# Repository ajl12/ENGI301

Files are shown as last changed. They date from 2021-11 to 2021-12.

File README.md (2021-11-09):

# Stress Buddy

The following repository contains files required to operate the Stress Buddy device created using a PocketBeagle.

For more information on how to build the device and connect hardware, visit: https://www.hackster.io/ajl12/stress-buddy-12f85d

# Initializing the PocketBeagle

To initialize the PocketBeagle, perform the following commands in the terminal:

1. sudo apt-get update
2. sudo apt-get install build-essential python-dev python-setuptools python-smbus -y
3. git clone https://github.com/adafruit/adafruit-beaglebone-io-python

# Code

To setup the code, pull the following repository from GitHub: https://github.com/ajl12/ENGI301

In the project_1 folder, 3 files are required to run the device. 

1. The configure_pins.sh file should be used by running the following command in the LINUX terminal:

	chmod 755 configure_pins.sh run

2. The project_1.py file contains the main code for running the device. 

3. The run file is needed to start the device. When ready to run the device, change directories  to var/lib/cloud9/ENGI301/project_1 and type the ./run command into the terminal. 

	Note: The run file also includes a python path to reference the ht16k33.py files under var/lib/cloud9/ENGI301/python

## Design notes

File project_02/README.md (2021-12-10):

# Stress Buddy

The following repository contains EAGLE, Gerber, and documentation files required to create a PCB for the Stress Buddy device.

To learn more about the Stress Buddy device and obtain instructions for low-fidelity breadboard assembly, visit: https://www.hackster.io/ajl12/stress-buddy-12f85d

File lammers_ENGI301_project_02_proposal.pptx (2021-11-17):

## ENGI 301 Stress Buddy PCB Proposal

11/16/21
Alex Lammers

## Background Information

- Stress Buddy Prototype
  - A toy that sits on your desk and with the push of a button, signals to your coworkers that you are stressed.
  - Main Hardware Components:
    - PocketBeagle Board
    - Transistor Array
    - Push Button
    - 4-Digit 7-Segment Display
    - 0-1 PSI Analog Pressure Sensor
    - Normally Closed Solenoid Valve
    - DC 3V Micro Vacuum Air Pump

Project Documentation Links
Hackster: https://www.hackster.io/ajl12/stress-buddy-12f85d
GitHub repository: https://github.com/ajl12/ENGI301/tree/main/project_1
What changes (if any) are you going to make based on your prototype?
Removing NPN transistor and incorporating it into the transistor array

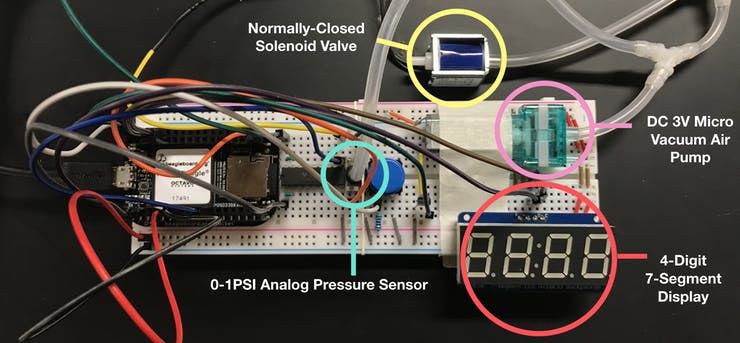
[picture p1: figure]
Main electrical hardware components of Stress Buddy.

## System Block Diagram

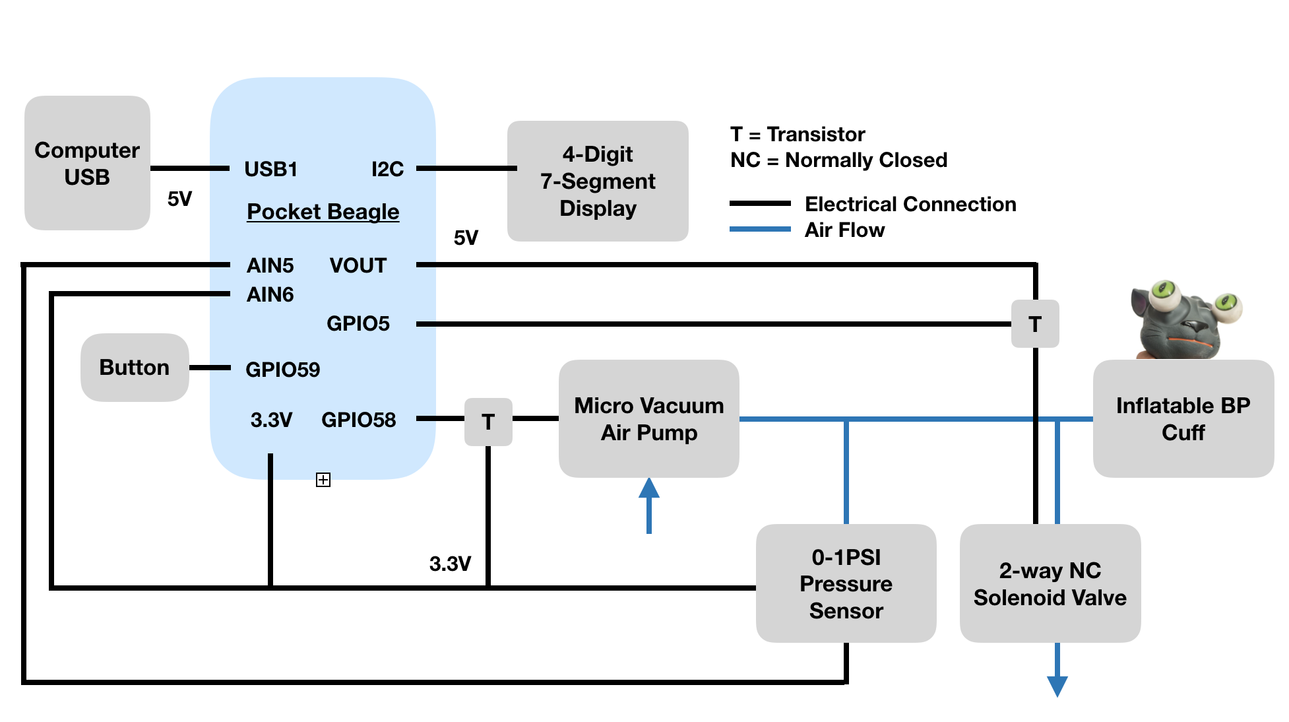
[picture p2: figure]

## Mechanical Block Diagram

Air tubing

2”

Hex Display

4”

Pocket Beagle

FRONT

1.1”

ULN2803AN

ULN2803AN

P1

3”

Solenoid Valve

Air Pump

BACK

Push
Button

USB

P2

1.38”

PS

2.17”

(primarily user interface components)

(components connected to tubing)

## Components Required

- List:
    - PocketBeagle Board
    - ULN2803AN Transistor Array
    - Push Button
    - Adafruit 0.56” 4-Digit 7-Segment Display
    - ABPDANN001PGAA5 0-1 PSI Analog Pressure Sensor
    - Normally Closed Solenoid Valve
    - DC 3V Micro Vacuum Air Pump

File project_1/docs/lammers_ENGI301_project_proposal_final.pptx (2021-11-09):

## ENGI 301

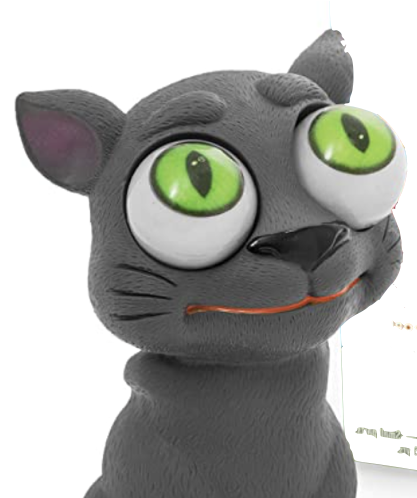
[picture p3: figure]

Stress Level

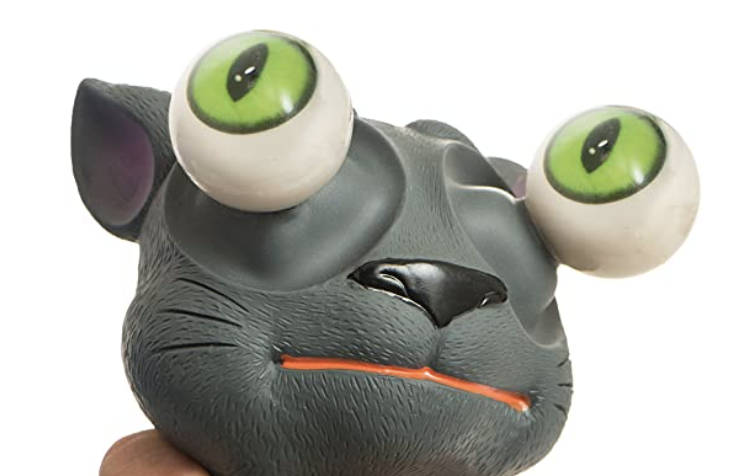
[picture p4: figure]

Stress Level

Stress-Level Indicator

10/05/13
Alex Lammers

## Background Information

Stress Level

- Working from home has naturally provided people their separate space to cope with work-related stress.
  - As people transition back to working in the office, there is a need for a light-hearted way of indicating that you still need your individual space during stressful times.
- Previous Projects to Draw On
  - Python Pressure Transducer Calibration with Manometer (https://github.com/makerportal/python-pressure-cal)
  - Blood Pressure Monitor (https://www.instructables.com/Blood-Pressure-Monitor/)
- Additions to Previous Projects
  - Holding a constant pressure through solenoid valve activation
  - Calculating pressure based voltage signals from analog pressure sensor.

Main Components:
- Solenoid valve
- Air pump
- Pressure Sensor
- Blood Pressure Cuff

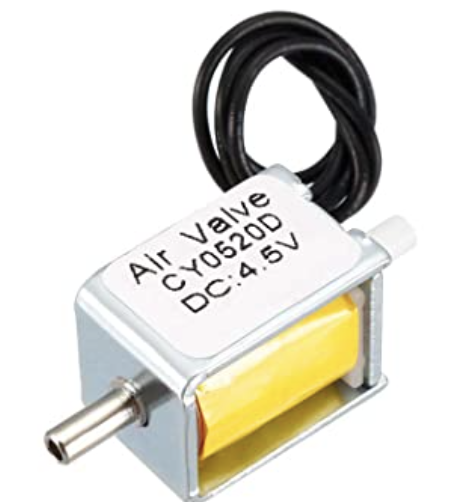
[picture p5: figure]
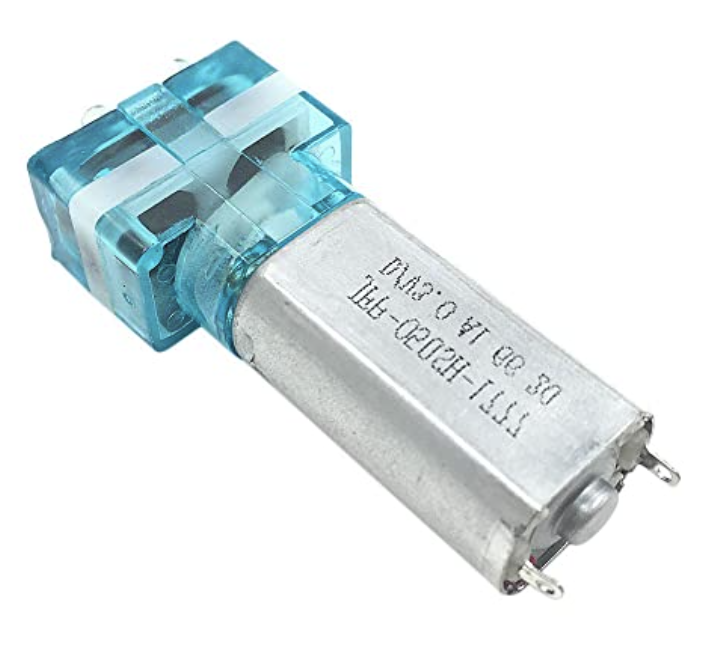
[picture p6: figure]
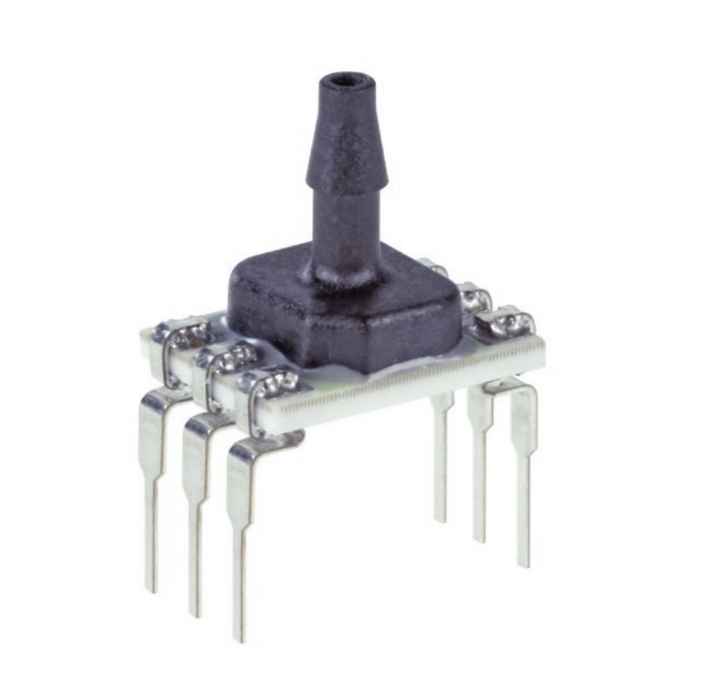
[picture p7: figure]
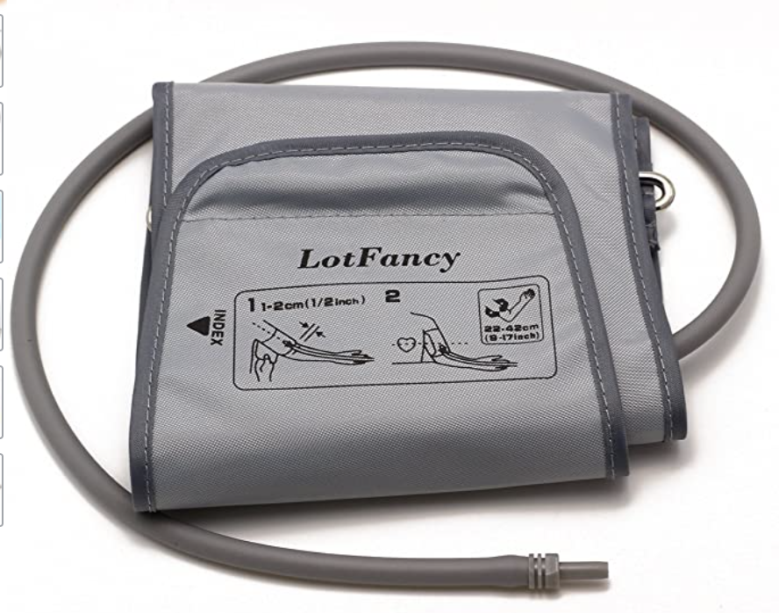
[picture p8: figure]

## System Block Diagram


Operating Procedure
1. User pushes button initiating start of air pump, pressure sensor measures pressure, LCD displays funny messages based on pressure readings
2. User pushes button again to pause inflation
3. User presses button again, solenoid opens, cuff fully decompresses

## Power Block Diagram

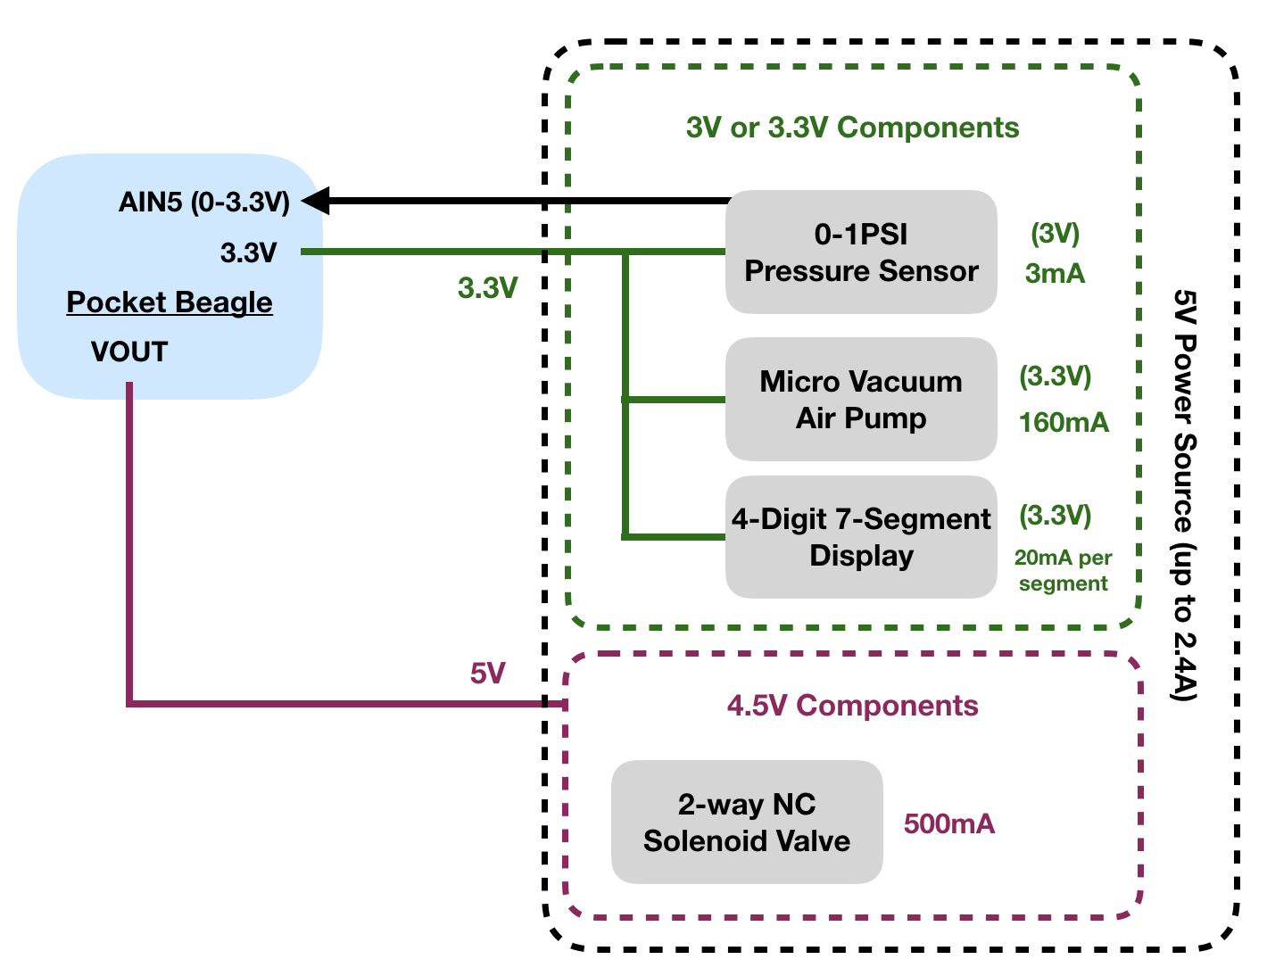
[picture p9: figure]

## Components / Budget

Component | Need to Buy | Cost
Lotfancy Large 9-17" D Ring Cuff Replacement (https://www.amazon.com/dp/B01FS37XP8) | 1 order | $10
AIMELIAE 1PCS DC 3V Micro Vacuum Air Pump Mini Air Pressure Pump Medical Pump 30KPa 0.28L (https://www.amazon.com/AIMELIAE-Micro-Vacuum-Pressure-Medical/dp/B074T95GGX) | 1 order | $12
uxcell Miniature Solenoid Valve 2 Way Normally Closed DC4.5V 0.5A Air Solenoid Valve, 2pcs (https://www.amazon.com/uxcell-Miniature-Solenoid-Normally-Closed/dp/B07WR8S4S1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) | 1 order (2 pieces) | $10
Honeywell Board Mount Pressure Sensor (https://www.mouser.com/ProductDetail/Honeywell/ABPDANN001PGAA5?qs=pAQS8nDEJVqzw9x6mmP6Eg%3D%3D)ABPDANN001PGAA5 (https://www.mouser.com/ProductDetail/Honeywell/ABPDANN001PGAA5?qs=pAQS8nDEJVqzw9x6mmP6Eg%3D%3D) | 1 order | $25
Feelers 2mm ID x 4mm OD High-Strength Silicone Tubing Thick Food Grade High Temp Pure Silicon Tube High Temp Home Brewing Winemaking Silicone Hose Tubing, 9.84ft Length (https://www.amazon.com/Feelers-High-Strength-Silicone-Silicon-Winemaking/dp/B08L81LM5B?s=industrial) | 1 order | $8
5000mAh 5V External Battery Power Pack 0.22lb (https://www.amazon.com/Alongza-Portable-Charger-10000mAh-External/dp/B082X53VDL?s=electronics) | 1 order | $20
Flippy Kitten Eye Popping Cat - Squishy Squeeze Toy for Stress Reduction (https://www.amazon.com/dp/B078KLTH1R) | 1 order | $14
| Total: | $99

Need all components to be purchased by instructor listed; additional components may be purchased by student

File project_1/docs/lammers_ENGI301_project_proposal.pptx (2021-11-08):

## ENGI 301


Stress Level


Stress Level

Stress-Level Indicator

10/05/13
Alex Lammers

## Background Information

Stress Level

- Working from home has naturally provided people their separate space to cope with work-related stress.
  - As people transition back to working in the office, there is a need for a light-hearted way of indicating that you still need your individual space during stressful times.
- Previous Projects to Draw On
  - Python Pressure Transducer Calibration with Manometer (https://github.com/makerportal/python-pressure-cal)
  - Blood Pressure Monitor (https://www.instructables.com/Blood-Pressure-Monitor/)
- Additions to Previous Projects
  - Holding a constant pressure through solenoid valve activation
  - Rescaling operational amplifier for 0-1.8V analog input pin

Main Components:
- Solenoid valve
- Air pump
- Pressure Sensor
- Blood Pressure Cuff


## System Block Diagram

Operating Procedure
1. User turns potentiometer until LCD displays desired pressure
2. User pushes button initiating start of air pump, 1st solenoid opens, LCD display continuously displays pressure
3. Pressure sensor detects desired pressure, 1st solenoid closes
4. User presses button again, 2nd solenoid opens, cuff fully decompresses

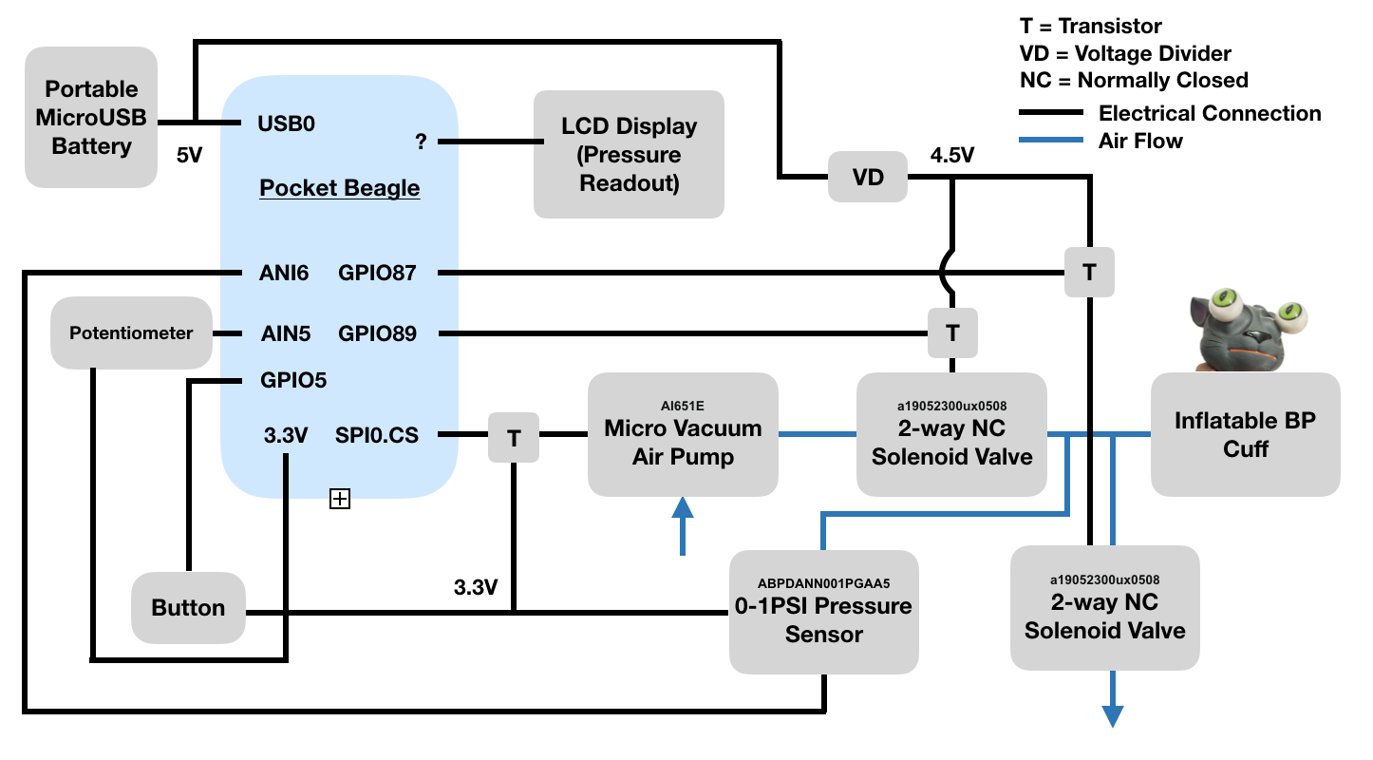
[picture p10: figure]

## Power Block Diagram

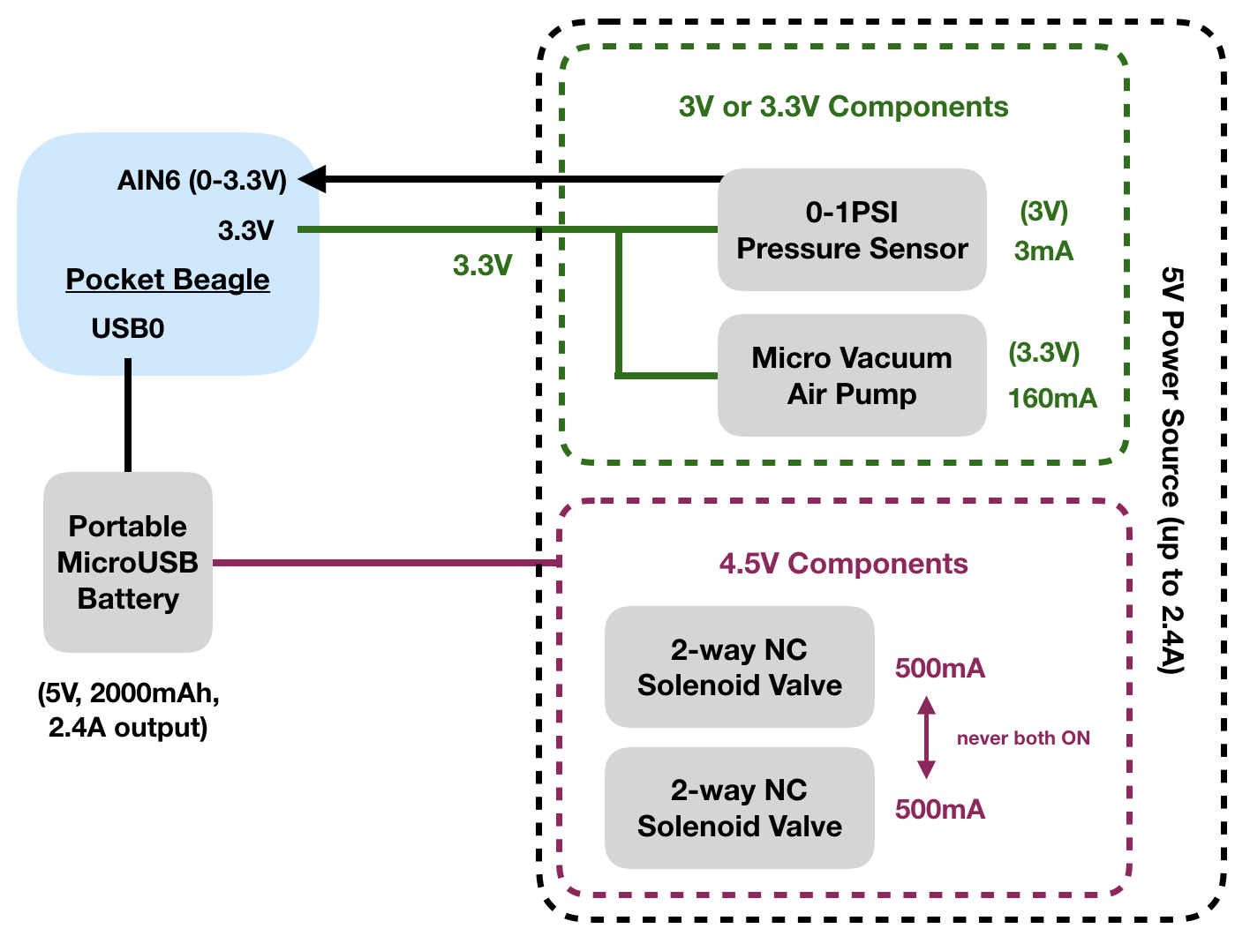
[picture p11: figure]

## Components / Budget

Component | Need to Buy | Cost
Lotfancy Large 9-17" D Ring Cuff Replacement (https://www.amazon.com/dp/B01FS37XP8) | 1 order | $10
AIMELIAE 1PCS DC 3V Micro Vacuum Air Pump Mini Air Pressure Pump Medical Pump 30KPa 0.28L (https://www.amazon.com/AIMELIAE-Micro-Vacuum-Pressure-Medical/dp/B074T95GGX) | 1 order | $12
uxcell Miniature Solenoid Valve 2 Way Normally Closed DC4.5V 0.5A Air Solenoid Valve, 2pcs (https://www.amazon.com/uxcell-Miniature-Solenoid-Normally-Closed/dp/B07WR8S4S1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) | 1 order (2 pieces) | $10
Honeywell Board Mount Pressure Sensor (https://www.mouser.com/ProductDetail/Honeywell/ABPDANN001PGAA5?qs=pAQS8nDEJVqzw9x6mmP6Eg%3D%3D)ABPDANN001PGAA5 (https://www.mouser.com/ProductDetail/Honeywell/ABPDANN001PGAA5?qs=pAQS8nDEJVqzw9x6mmP6Eg%3D%3D) | 1 order | $25
Feelers 2mm ID x 4mm OD High-Strength Silicone Tubing Thick Food Grade High Temp Pure Silicon Tube High Temp Home Brewing Winemaking Silicone Hose Tubing, 9.84ft Length (https://www.amazon.com/Feelers-High-Strength-Silicone-Silicon-Winemaking/dp/B08L81LM5B?s=industrial) | 1 order | $8
5000mAh 5V External Battery Power Pack 0.22lb (https://www.amazon.com/Alongza-Portable-Charger-10000mAh-External/dp/B082X53VDL?s=electronics) | 1 order | $20
Flippy Kitten Eye Popping Cat - Squishy Squeeze Toy for Stress Reduction (https://www.amazon.com/dp/B078KLTH1R) | 1 order | $14
| Total: | $99

Need all components to be purchased by instructor listed; additional components may be purchased by student

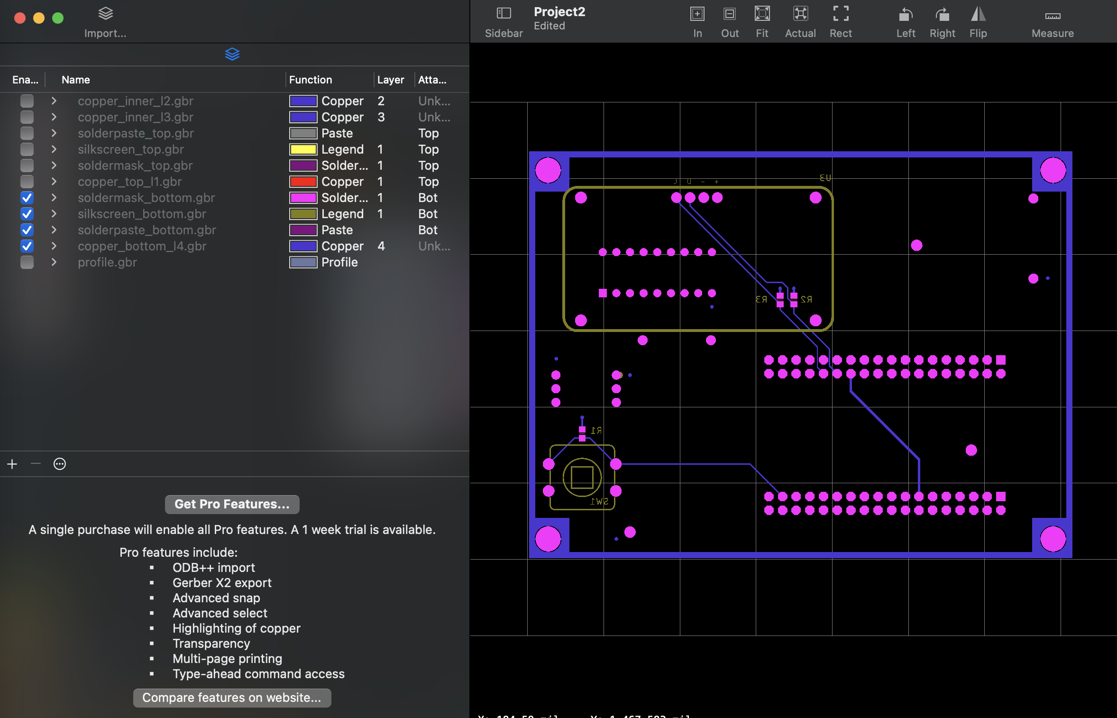
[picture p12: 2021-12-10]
project_02/docs/bottom_gerber.png

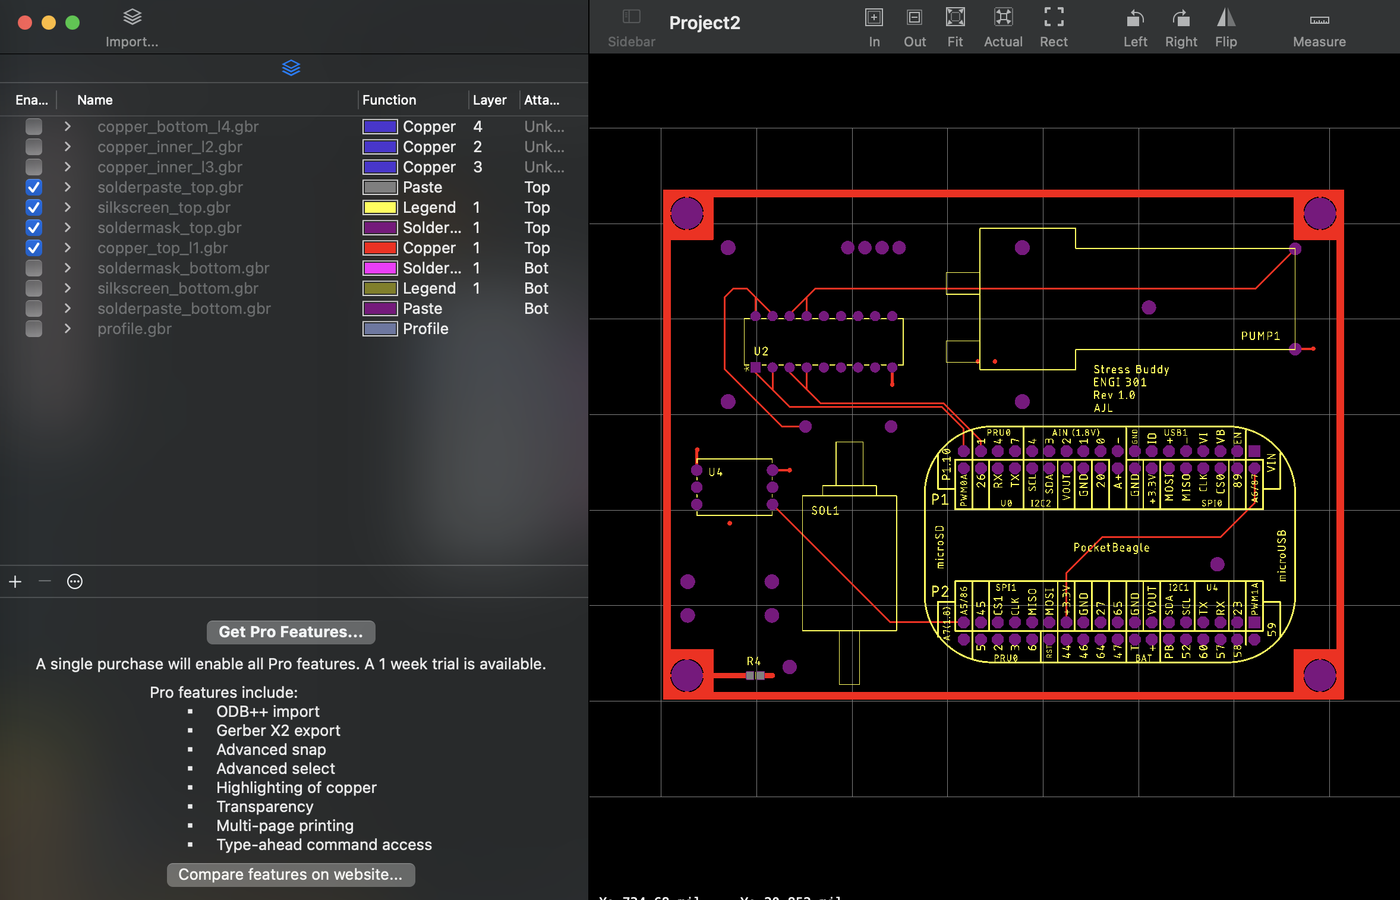
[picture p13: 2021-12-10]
project_02/docs/top_gerber.png

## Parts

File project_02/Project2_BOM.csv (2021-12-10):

Qty | Value | Device | Package | Parts | Description | COPYRIGHT | MANUFACTURER_PART_NUMBER | MFR_NAME
1 | 0.1 | R_R0603 | R0603 | R4 | RESISTOR, American symbol
1 | 0.56_HEX_BACKPACK | 0.56_HEX_BACKPACK | 0.56_HEX_BACKPACK | U3 | 0.56 LED HEX Backback - Adafruit HT16K33 -"
3 | 1k | R_R0603 | R0603 | R1, R2, R3 | RESISTOR, American symbol
1 | ABPDANT001PGAA5 | ABPDANT001PGAA5 | ABPDAN_HNW | U4 |  | Copyright (C) 2021 Ultra Librarian. All rights reserved. | ABPDANT005PGAA5 | Honeywell
1 | AIRPUMP | AIRPUMP | AIRPUMP | PUMP1 | AIMELIAE 1PCS DC 3V Micro Vacuum Air Pump Mini Air Pressure Pump Medical Pump 30KPa 0.28L -
6 | FIDUCIAL | FIDUCIAL | FIDUCIAL_40MIL | FUD1, FUD2, FUD3, FUD4, FUD5, FUD6
4 | MOUNTING_HOLE | MOUNTING_HOLE | MOUNTING_HOLE | MGT1, MGT2, MGT3, MGT4 | Chassis Mounting Hole w/GND connection ability
1 | POCKETBEAGLE_REL | POCKETBEAGLE_REL | POCKETBEAGLE | U1 | A PocketBeagle device with relevant components for the Stress Buddy project separated from the main schematic.
1 | PUSH_BUTTON | PUSH_BUTTON | BUTTON_12.5MM | SW1
1 | SOLENOID | SOLENOID | SOLENOID | SOL1 | Uxcell Miniature Solenoid Valve 2 Way Normally Closed DC4.5V 0.5A Air Solenoid Valve -
1 | ULN2803AN | ULN2803AN | N18_TEX | U2 |  | Copyright (C) 2021 Ultra Librarian. All rights reserved. | ULN2803AN | Texas Instruments

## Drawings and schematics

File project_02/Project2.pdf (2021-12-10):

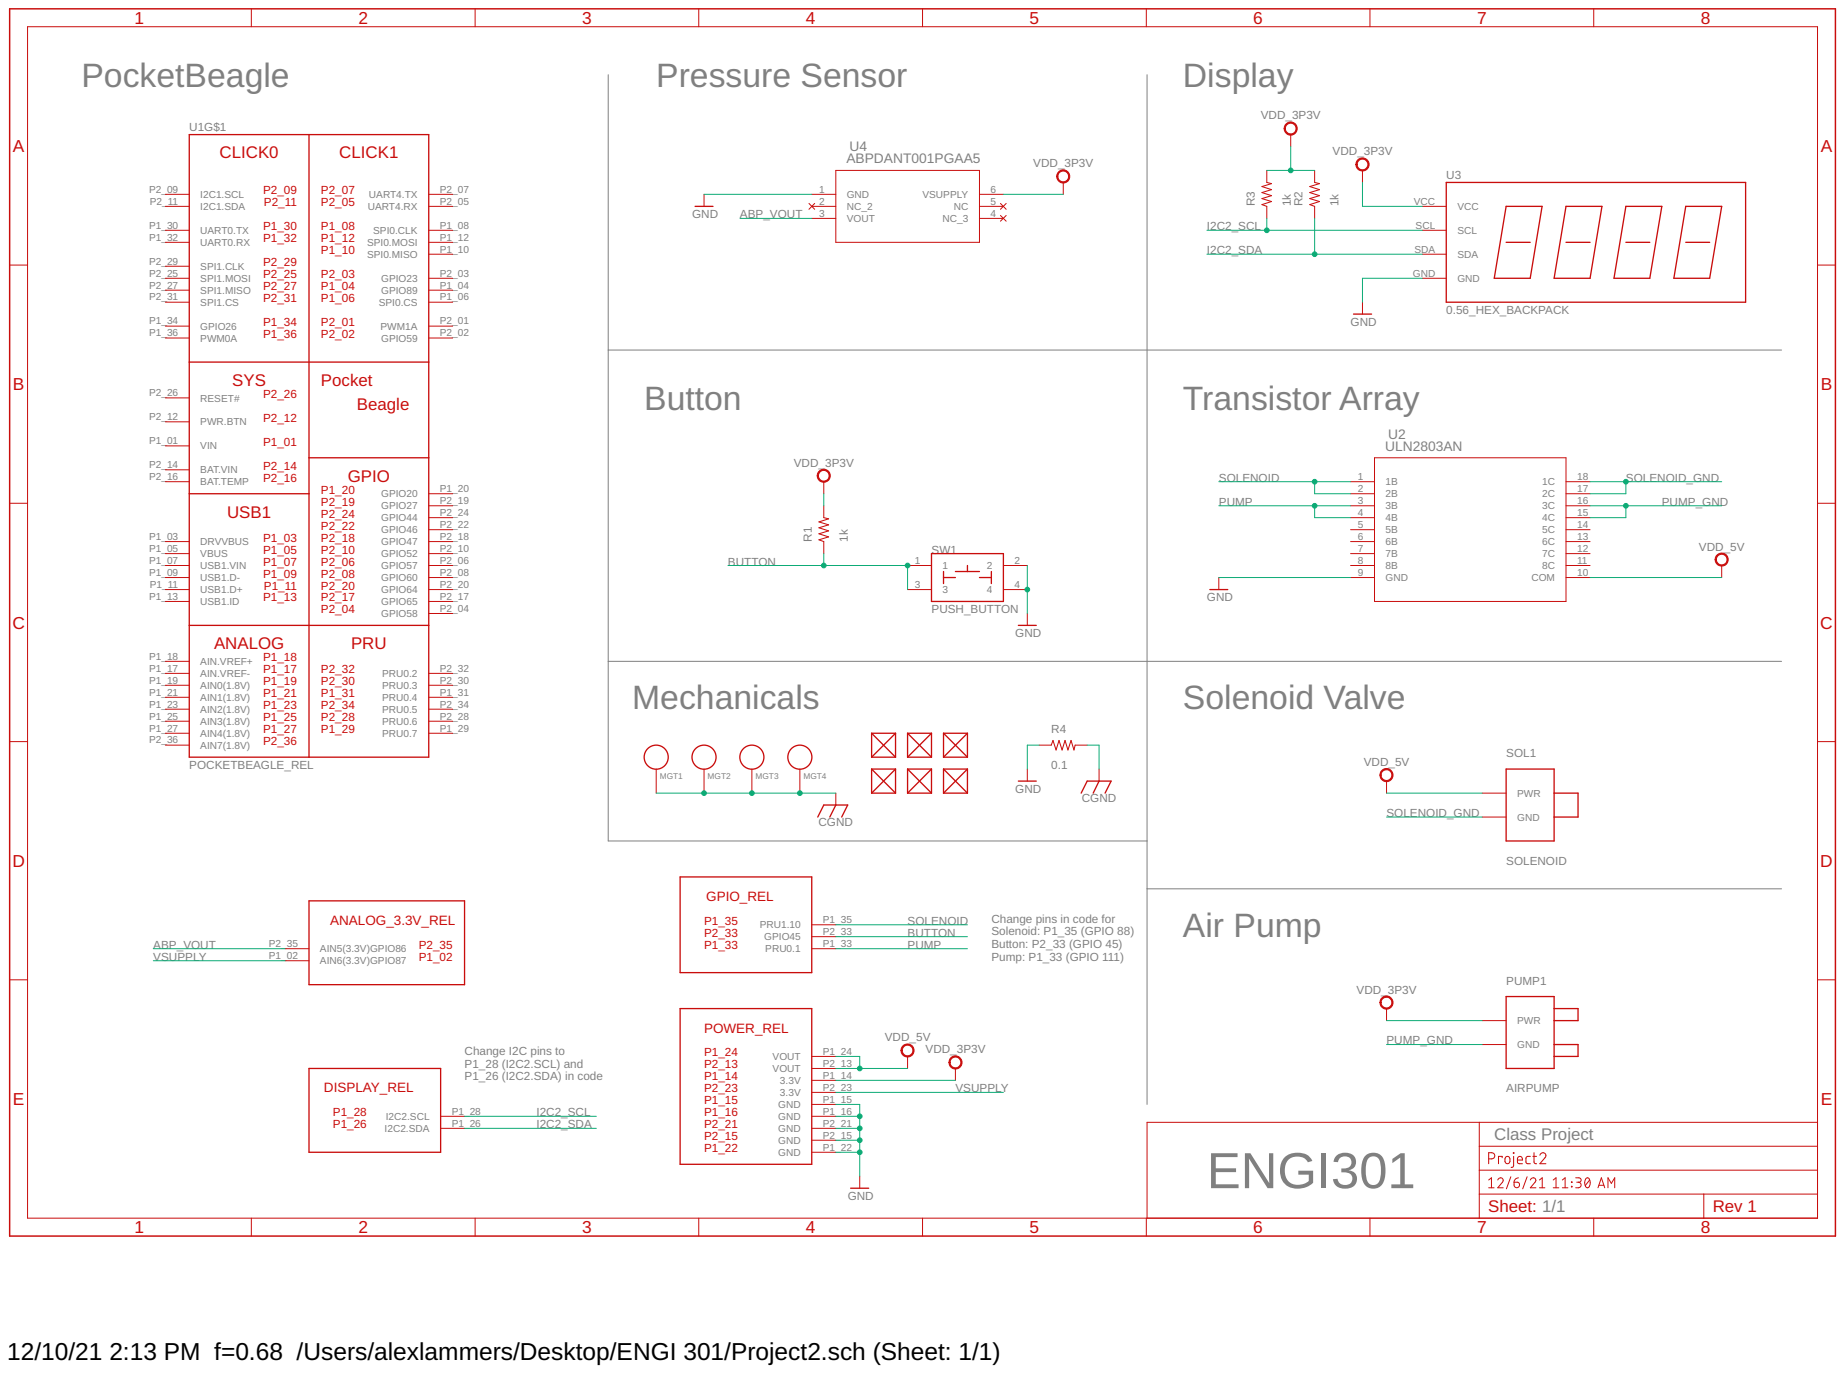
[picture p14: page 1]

CLICK0 I2C1.SCL P2_09 UART0.TX P2_09 P2_11 I2C1.SDA P1_30 P1_32 P1_34 P2_29 SPI1.MOSI P2_25 SPI1.MISO P1_36 P2_25 P2_27 P2_31 | CLICK1 P2_07 P2_05 UART4.RX P1_08 P1_12 GPIO89 P1_10 P2_03 P1_04 P1_06 SPI0.CS P2_01 P2_02 | P2_05 UART4.TX P1_04 SPI0.CLK P1_08 SPI0.MISO

SYS RESET# P2_26 P2_26 PWR.BTN P2_12 P1_01 VIN P2_14 P2_16 | Pocket Beagle

Change pins in code for Solenoid: P1_35 (GPIO 88) Button: P2_33 (GPIO 45) Pump: P1_33 (GPIO 111)

Change I2C pins to P1_28 (I2C2.SCL) and P1_26 (I2C2.SDA) in code

12/10/21 2:13 PM f=0.68 /Users/alexlammers/Desktop/ENGI 301/Project2.sch (Sheet: 1/1)

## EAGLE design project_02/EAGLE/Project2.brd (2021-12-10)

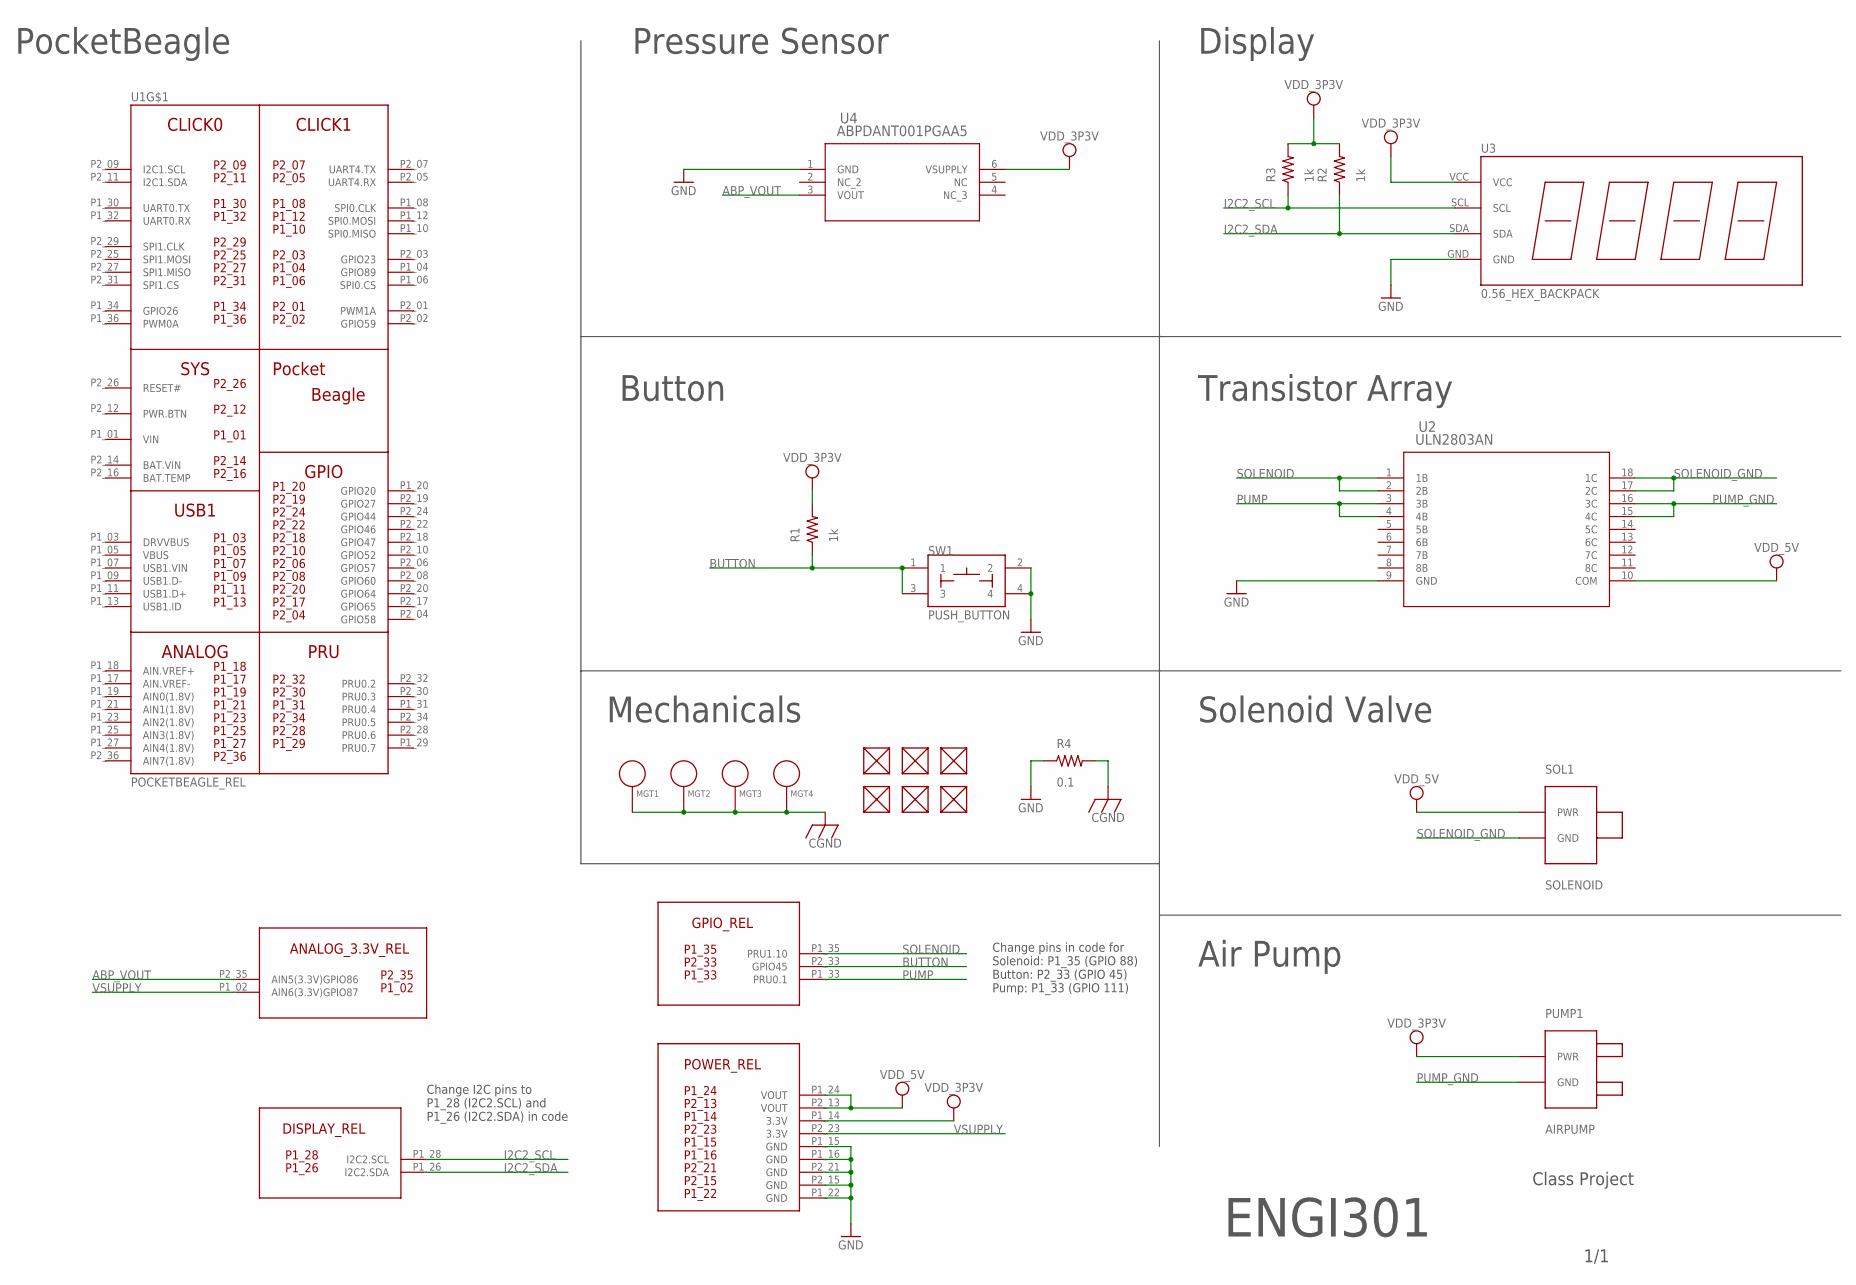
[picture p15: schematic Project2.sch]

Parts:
FUD1, FUD2, FUD3, FUD4, FUD5, FUD6: FIDUCIAL; FIDUCIAL_40MIL
MGT1, MGT2, MGT3, MGT4: MOUNTING_HOLE
PUMP1: AIRPUMP
R1, R2, R3: 1k; R0603
R4: 0.1; R0603
SOL1: SOLENOID
SW1: PUSH_BUTTON; BUTTON_12.5MM
U1: POCKETBEAGLE_REL; POCKETBEAGLE
U2: ULN2803AN; N18_TEX
U3: 0.56_HEX_BACKPACK
U4: ABPDANT001PGAA5; ABPDAN_HNW

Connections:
ABP_VOUT: U1.P2_35 (AIN5(3.3V)GPIO86), U4.3 (VOUT)
BAT.VIN: U1.P2_14 (BAT.VIN)
BUTTON: R1.1, SW1.1, SW1.3, U1.P2_33 (GPIO45)
CGND: MGT1.P$1, MGT2.P$1, MGT3.P$1, MGT4.P$1, R4.2
GND: R4.1, SW1.2, SW1.4, U1.P1_15 (GND), U1.P1_16 (GND), U1.P1_22 (GND), U1.P2_15 (GND), U1.P2_21 (GND), U2.9 (GND), U3.GND, U4.1 (GND)
I2C2_SCL: R3.1, U1.P1_28 (I2C2.SCL), U3.SCL
I2C2_SDA: R2.1, U1.P1_26 (I2C2.SDA), U3.SDA
PUMP: U1.P1_33 (PRU0.1), U2.3 (3B), U2.4 (4B)
PUMP_GND: PUMP1.GND1 (GND), U2.15 (4C), U2.16 (3C)
SOLENOID: U1.P1_35 (PRU1.10), U2.1 (1B), U2.2 (2B)
SOLENOID_GND: SOL1.GND, U2.17 (2C), U2.18 (1C)
VDD_3P3V: PUMP1.PWR1 (PWR), R1.2, R2.2, R3.2, U1.P1_14 (3.3V), U3.VCC, U4.6 (VSUPPLY)
VDD_5V: SOL1.PWR1 (PWR), U1.P1_24 (VOUT), U1.P2_13 (VOUT), U2.10 (COM)
VIN: U1.P1_01 (VIN)
VSUPPLY: U1.P1_02 (AIN6(3.3V)GPIO87), U1.P2_23 (3.3V)

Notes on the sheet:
PocketBeagle
Pressure Sensor
Button
Transistor Array
Display
Solenoid Valve
Air Pump
ENGI301
Class Project
1/1
Mechanicals
Change I2C pins to P1_28 (I2C2.SCL) and P1_26 (I2C2.SDA) in code
Change pins in code for Solenoid: P1_35 (GPIO 88) Button: P2_33 (GPIO 45) Pump: P1_33 (GPIO 111)

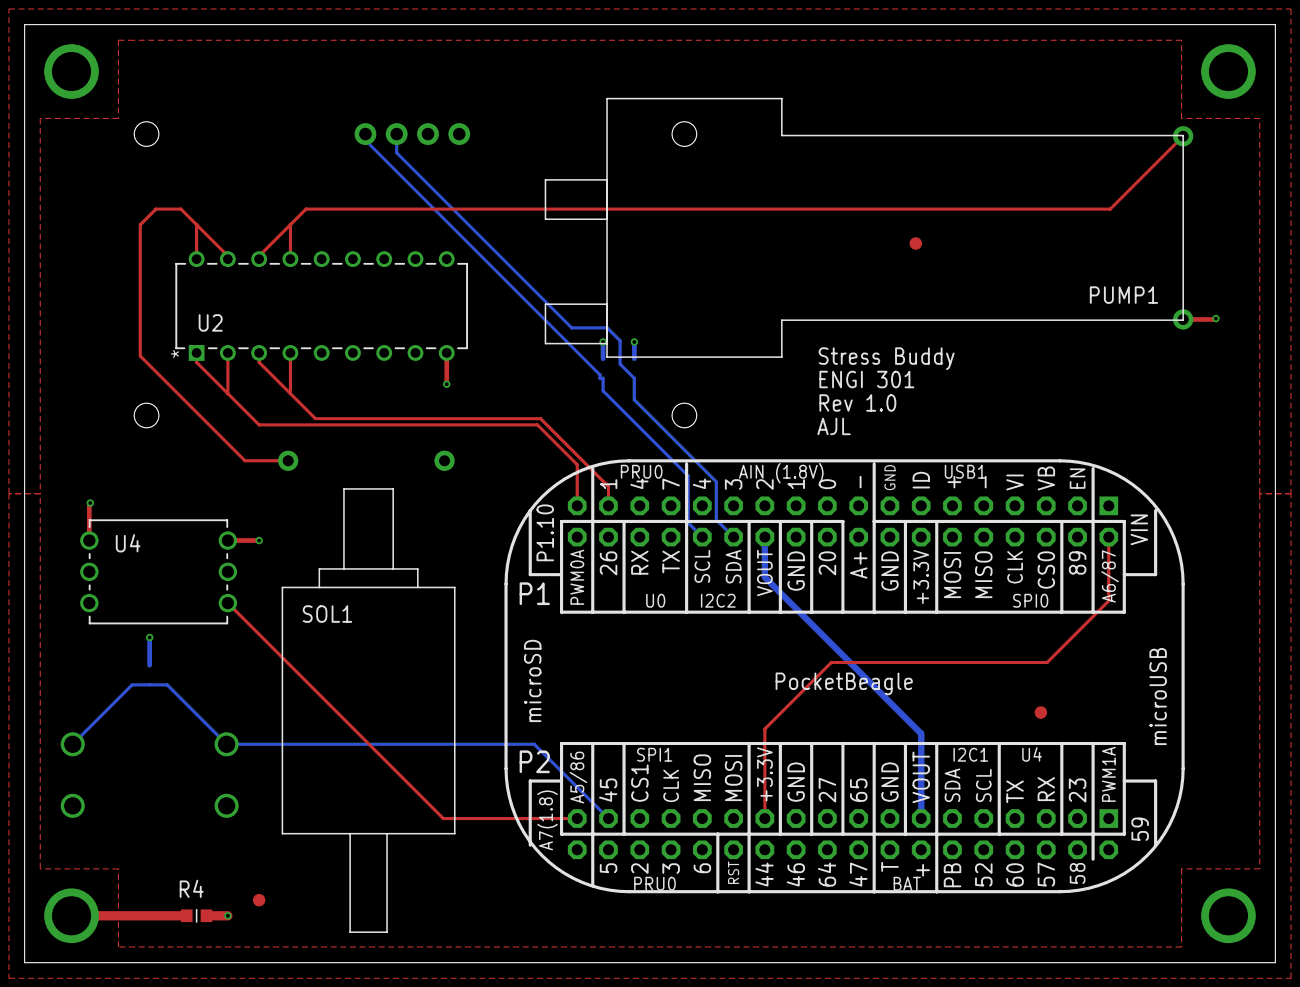
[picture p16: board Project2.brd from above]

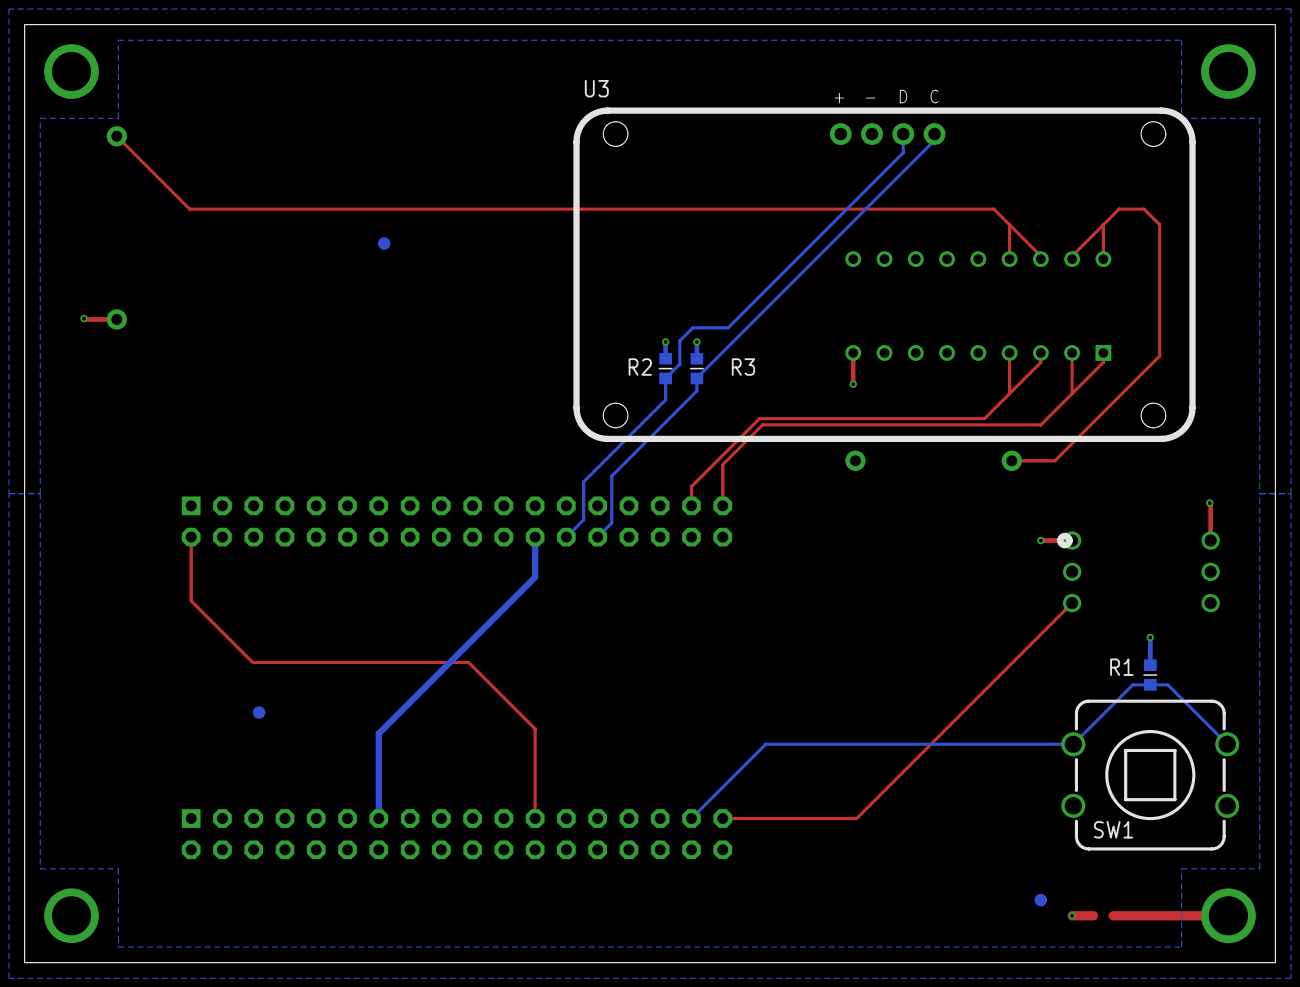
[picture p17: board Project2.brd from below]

Board: 4 copper layers, 101.6 x 76.2 mm, 21 parts (8 on the bottom side), 13 nets.

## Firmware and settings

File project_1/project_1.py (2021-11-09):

"""
--------------------------------------------------------------------------
Stress Buddy
--------------------------------------------------------------------------
License:   
Copyright 2021 Alex Lammers

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
1. Redistributions of source code must retain the above copyright notice, this 
list of conditions and the following disclaimer.

2. Redistributions in binary form must reproduce the above copyright notice, 
this list of conditions and the following disclaimer in the documentation 
and/or other materials provided with the distribution.

3. Neither the name of the copyright holder nor the names of its contributors 
may be used to endorse or promote products derived from this software without 
specific prior written permission.

THIS SOFTWARE IS PROVIDED BY THE COPYRIGHT HOLDERS AND CONTRIBUTORS "AS IS" 
AND ANY EXPRESS OR IMPLIED WARRANTIES, INCLUDING, BUT NOT LIMITED TO, THE 
IMPLIED WARRANTIES OF MERCHANTABILITY AND FITNESS FOR A PARTICULAR PURPOSE ARE 
DISCLAIMED. IN NO EVENT SHALL THE COPYRIGHT HOLDER OR CONTRIBUTORS BE LIABLE 
FOR ANY DIRECT, INDIRECT, INCIDENTAL, SPECIAL, EXEMPLARY, OR CONSEQUENTIAL 
DAMAGES (INCLUDING, BUT NOT LIMITED TO, PROCUREMENT OF SUBSTITUTE GOODS OR 
SERVICES; LOSS OF USE, DATA, OR PROFITS; OR BUSINESS INTERRUPTION) HOWEVER 
CAUSED AND ON ANY THEORY OF LIABILITY, WHETHER IN CONTRACT, STRICT LIABILITY, 
OR TORT (INCLUDING NEGLIGENCE OR OTHERWISE) ARISING IN ANY WAY OUT OF THE USE 
OF THIS SOFTWARE, EVEN IF ADVISED OF THE POSSIBILITY OF SUCH DAMAGE.
--------------------------------------------------------------------------

Use the following hardware components to make this device:  
  - HT16K33 Display
  - Button
  - Micro Air Pump
  - Normally-Closed Solenoid Valve
  - 0-1 PSI analog pressure sensor
  
Requirements:
  - Hardware:
    - User Interface: 
        - When button is pressed, turn on the air pump to inflate blood pressure cuff
        - When button is pressed a second time, turn off pump
        - When button is pressed a third time, open solenoid valve to release air 
    - While cuff is inflating: Monitor air pressure and display messages based on pressure readings
    - While cuff is deflating: Monitor air pressure and display messages based on pressure readings
    - When pressure readings indicate full deflation: Reset solenoid valve

Uses:
  - Modified HT16K33 display library (based on file from Copyright 2020 Erik Welsh)

"""
import time
import os

import Adafruit_BBIO.GPIO as GPIO
import Adafruit_BBIO.ADC as ADC
import Adafruit_BBIO.PWM as PWM

import ht16k33 as HT16K33


# ------------------------------------------------------------------------
# Constants
# ------------------------------------------------------------------------

# None

# ------------------------------------------------------------------------
# Global variables
# ------------------------------------------------------------------------

# None

# ------------------------------------------------------------------------
# Functions / Classes
# ------------------------------------------------------------------------

class InflationDevice():
    """ InflationDevice """

    button1  = None
    button2 = None
    pump    = None
    reset_time = None
    solenoid_1 = None
    v_supply = None
    display    = None

    def __init__(self, button1="P2_2", button2="P2_8", pump="P2_4", reset_time=0.5, solenoid_1="P1_6",v_supply="P1_2",i2c_bus=1,i2c_address=0x70):
        """ Initialize variables """

        self.button1    = button1
        self.button2    = button2
        self.pump       = pump
        self.reset_time = reset_time
        self.solenoid_1 = solenoid_1
        self.v_supply   = v_supply
        self.display    = HT16K33.HT16K33(i2c_bus, i2c_address)

        self._setup()

    # End def


    def _setup(self):
        """Setup the hardware components."""

        # Initialize Button
        GPIO.setup(self.button1, GPIO.IN)
        GPIO.setup(self.button2, GPIO.IN)

        # Initialize Pump
        GPIO.setup(self.pump, GPIO.OUT)
        
        # Initialize Solenoid Valve
        GPIO.setup(self.solenoid_1, GPIO.OUT)
        
        # Initialize Display
        self.display.set_digit(0, 0)        # "0" 
        self.display.set_digit(1, 0)        # "0"
        self.display.set_digit(2, 0)        # "0"
        self.display.set_digit(3, 0)        # "0"
        
    def read_v_out(self):
        """Read the v_out voltage of the pressure sensor:
               - Return raw analog value from input pin 
        """
        
        # Return raw value from system path 
        return int(os.popen("cat /sys/bus/iio/devices/iio\:device0/in_voltage5_raw").read())
    
    #End def
    
    def read_v_supply(self):
        """Read the v_supply voltage of the pressure sensor:
               - Return raw analog value from input pin 
        """
        
        # Return raw value from system path
        return int(os.popen("cat /sys/bus/iio/devices/iio\:device0/in_voltage6_raw").read())
    
    #End def
    
    def messages(self,pressure):
        """Display funny messages about stress intensity based on pressure reading input:
               - Classify pressure input in specified ranges
                    - 0-30 mmHg : "COOL"
                    - 30-40 mmHg : "OOOP"
                    - 40-50 mmHg : "AHHH"
                    - >50 mmHg : "HELP"
                - Update display with corresponding messages
        """
        
        if (pressure > 50):
            self.display.set_digit(0, 13)        # "H"
            self.display.set_digit(1, 11)        # "E"
            self.display.set_digit(2, 14)        # "L"
            self.display.set_digit(3, 12)        # "P"
        elif (pressure > 40):
            self.display.set_digit(0, 10)        # "A"
            self.display.set_digit(1, 13)        # "H"
            self.display.set_digit(2, 13)        # "H"
            self.display.set_digit(3, 13)        # "H"
        elif (pressure > 30): 
            self.display.set_digit(0, 0)         # "O"
            self.display.set_digit(1, 0)         # "O"
            self.display.set_digit(2, 0)         # "O"
            self.display.set_digit(3, 12)        # "P"
        else: 
            self.display.set_digit(0, 15)        # "C"
            self.display.set_digit(1, 0)         # "O"
            self.display.set_digit(2, 0)         # "O"
            self.display.set_digit(3, 14)        # "L"
        
    # End def

    def run(self):
        """Execute the main program."""

        # Air pump OFF
        GPIO.output(self.pump, GPIO.LOW)
        
        # Solenoid valve OFF (Closed)
        GPIO.output(self.solenoid_1, GPIO.LOW)
        
        # Read voltage measured at v_out pin of pressure sensor
        v_out = self.read_v_out()

        while(1):

            # Wait for button press
            while(GPIO.input(self.button1) == 1):
                time.sleep(0.1)
                
            time.sleep(0.5)
            
            # Air pump ON
            GPIO.output(self.pump, GPIO.HIGH)
            
            # Wait for button press
            while(GPIO.input(self.button1) == 1):
              
                # Calculate pressure in mmHg based on v_out and supply measurements
                v_out = self.read_v_out() 
                v_supply = self.read_v_supply()
                pressure = abs(round(57.7149*((v_out - 0.1*v_supply)/(0.8*v_supply))))
                
                # Update the display
                self.messages(pressure) 
                time.sleep(0.1)
               
            time.sleep(0.5)
            
            # Air pump OFF
            GPIO.output(self.pump, GPIO.LOW)
            
            # Wait for button press
            while(GPIO.input(self.button1) == 1):
                time.sleep(0.5)
                
            time.sleep(0.1)
            
            # Solenoid valve ON (Open)
            GPIO.output(self.solenoid_1, GPIO.HIGH)
            
            # Air pump OFF
            GPIO.output(self.pump, GPIO.LOW)
            
            # Wait until pressure cuff has fully released compressed air and is below a v_out singal from the pressure sensor of 500mV. 
            while(v_out > 500):
              
                # Calculate pressure in mmHg based on v_out and supply measurements
                v_out = self.read_v_out()
                v_supply = self.read_v_supply()
                pressure = abs(round(57.7149*((v_out - 0.1*v_supply)/(0.8*v_supply))))
                
                # Update the display
                self.messages(pressure)
                time.sleep(0.1)
                
            # Solenoid valve OFF (Closed)
            GPIO.output(self.solenoid_1, GPIO.LOW)
  
    def cleanup(self):
        """Cleanup the hardware components."""

        # Clean up GPIOs
        GPIO.output(self.pump, GPIO.LOW)
        GPIO.output(self.solenoid_1, GPIO.LOW)

        # Clean up GPIOs
        GPIO.cleanup()
        
        # Set Display to something fun to show program is complete
        self.display.set_digit(0, 0)        # "0" 
        self.display.set_digit(1, 0)        # "0"
        self.display.set_digit(2, 0)        # "0"
        self.display.set_digit(3, 0)        # "0"

    # End def

# End class

# ------------------------------------------------------------------------
# Main script
# ------------------------------------------------------------------------

if __name__ == '__main__':

    print("Program Start")

    # Create instantiation of the lock
    project_1 = InflationDevice()

    try:
        # Run the Stress Buddy
        project_1.run()

    except KeyboardInterrupt:
        # Clean up hardware when exiting
        project_1.cleanup()
        
        print("Program Complete")

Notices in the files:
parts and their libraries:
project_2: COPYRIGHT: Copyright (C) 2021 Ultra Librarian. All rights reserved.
